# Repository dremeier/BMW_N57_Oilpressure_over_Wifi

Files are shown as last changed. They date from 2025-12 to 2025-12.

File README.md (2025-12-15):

# BMW N57 Oilpressure over WiFi

Öldruck- und Öltemperaturanzeige für BMW N57 Motoren auf Basis eines ESP32  
mit eigenem PCB, VDO-Öldrucksensor und Web-UI (Dark-OLED / Kombiinstrument-Stil).

---
## 📸 Projektüberblick

### Komplettsystem – Steuergerät & Sensor
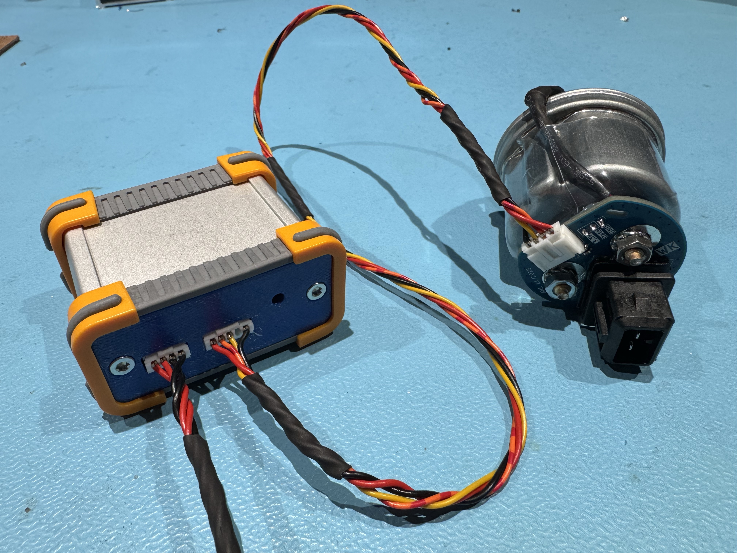
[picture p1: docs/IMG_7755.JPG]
Systemübersicht


Das System besteht aus einem ESP32-Steuergerät und einer separaten
Sensorplatine, die direkt am VDO-Öldruckgeber montiert ist.  
Die Anzeige erfolgt drahtlos über ein integriertes Web-Interface.

---
### Steuergerät (ESP32-S3 Mini)
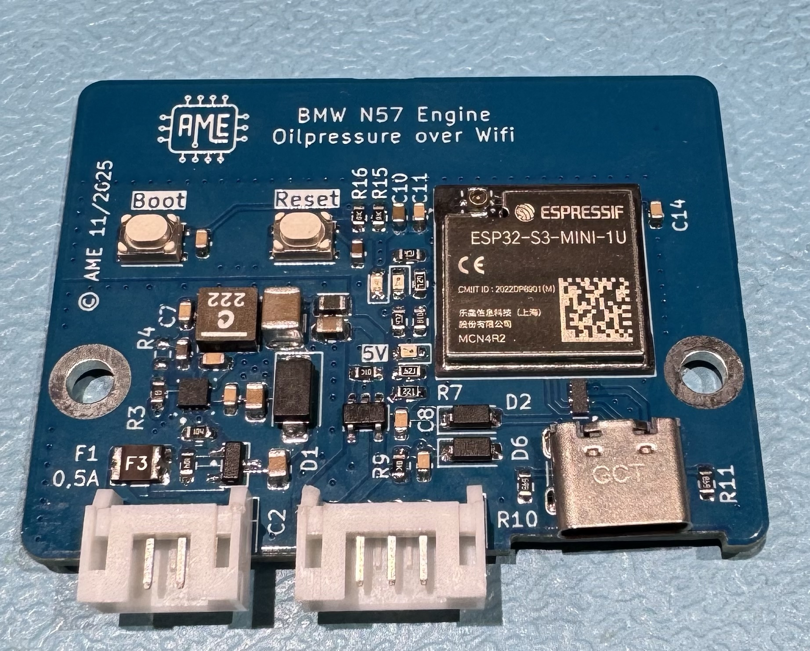
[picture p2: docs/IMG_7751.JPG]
ESP32 Steuergerät


## Features

- Messung des **Öldrucks (0–5 bar)** über VDO Druckgeber  
- Messung der **Öltemperatur** (DS18B20)  
- **ESP32 Web-Interface** (kein Internet erforderlich)  
- Automatisches **Tag-/Nacht-Design** (Grün / BMW-Amber)  
- Analoge Rundinstrument-Anzeige (Skala 0–5 bar)  
- Warnlogik:  
  - Öldruck < 0,8 bar → blinkende Warnanzeige  
  - Öltemperatur > Schwellwert → Warnfarbe  
- Integriertes **Debug-Overlay** (ADC, Spannung, Widerstände, Versionen)

---

### VDO Öldruckgeber montiert
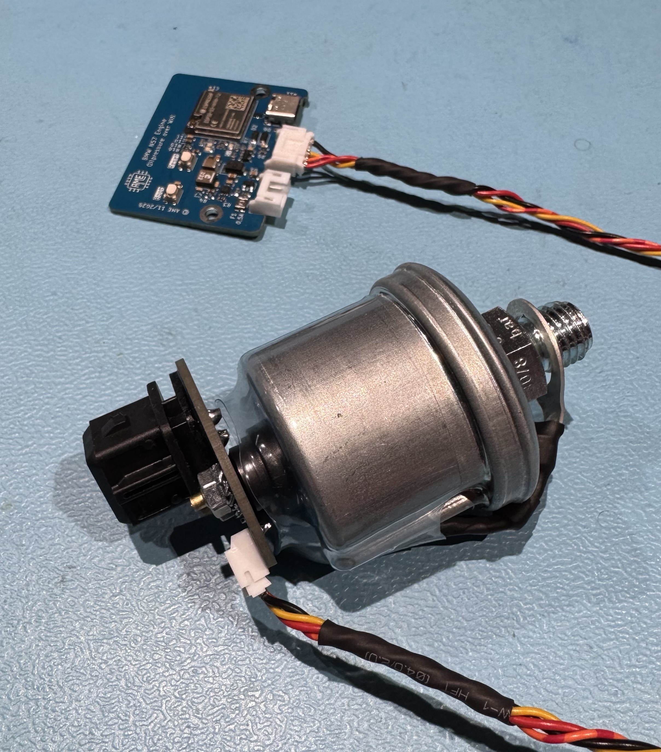
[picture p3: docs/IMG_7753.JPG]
VDO Drucksensor


OEM-naher VDO-Öldruckgeber mit integrierter Elektronik und KFZ-tauglicher
Montage.

---

## Projektstruktur

```text
BMW_N57_OILPRESSURE_OVER_WIFI/
├─ firmware/          ESP32 Firmware (PlatformIO)
├─ pcb_main/          Hauptplatine (KiCad)
├─ pcb_sensor/        Sensorplatine (KiCad)
├─ docs/              Datenblätter & Dokumentation
└─ README.md
```

---
### 3D-Render – Hauptplatine
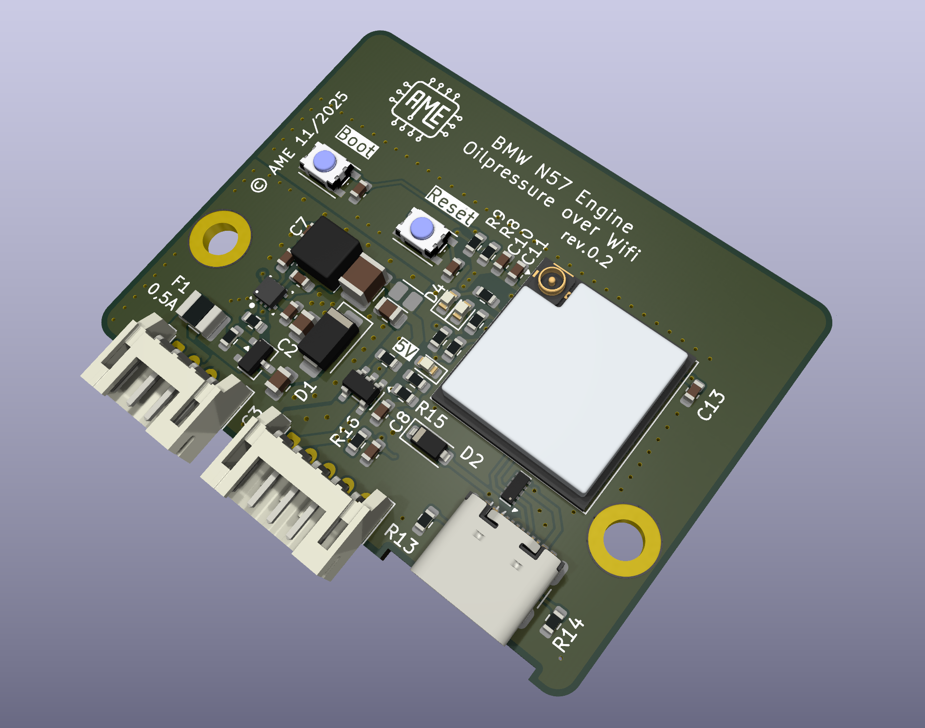
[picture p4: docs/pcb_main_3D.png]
PCB 3D Render


3D-Ansicht der Hauptplatine (KiCad).  
Kompaktes, robustes Layout für den Einsatz im Fahrzeug.

## Hardware

- ESP32 (ESP32-S3 mini)
- VDO Öldruckgeber 0–5 bar (M12x1.5)
- DS18B20 Temperatursensor
- Step‑Down‑Regler 
- Versorgung Sensor: **≈ 5,0 V**
- USB‑C zum flaschen

## 🚦 Status-LEDs

| LED | Funktion |
|----|---|
| **LED orange** | Leuchtet dauerhaft, wenn der WiFi-Access-Point aktiv ist |
| **LED blau** | Leuchtet, sobald ein Client (Smartphone / Browser) verbunden ist |

---

## Messprinzip

Der VDO-Öldruckgeber arbeitet als Widerstand gegen Masse.  
Die Messung erfolgt über einen Spannungsteiler:

```text
+5V → R_PULLUP → Rsensor → GND
```

Die Firmware berechnet:
1. ADC → Spannung (kalibriert)
2. Spannung → Rsensor
3. Rsensor → bar (VDO-Kennlinie via LUT + Interpolation)
4. IIR-Filter zur Glättung

---
### Web-UI (Live-Anzeige)
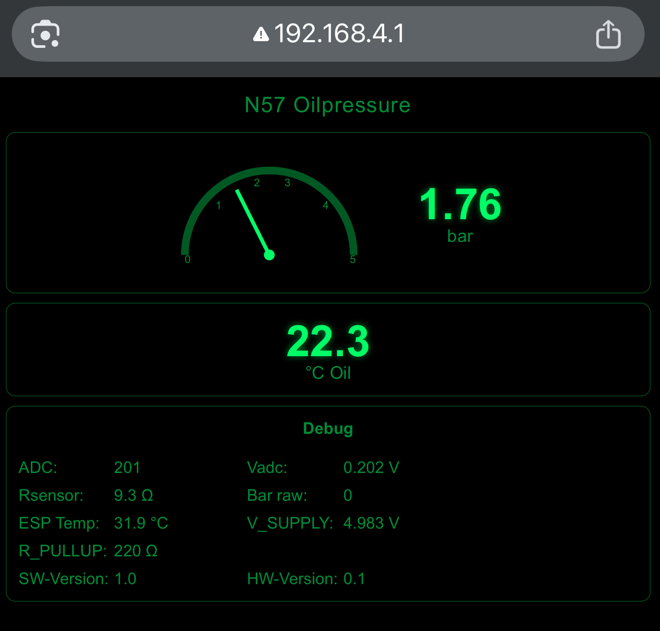
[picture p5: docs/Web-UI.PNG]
Web UI


## Web-UI

- Zugriff über ESP32 Access Point
- Anzeige:
  - Öldruck (bar)
  - Öltemperatur (°C)
  - Analoges Rundinstrument
- Debug-Bereich mit:
  - ADC
  - Vadc
  - Rsensor
  - Bar raw
  - ESP-Temperatur
  - Versorgungsspannung
  - Pullup-Widerstand
  - SW- / HW-Version

---

## Status

- Hardware: **funktionsfähig**
- Firmware: **stabil**
- Kalibrierung: **ADC + Versorgungsspannung kalibriert**
- Projektstatus: **aktiv in Entwicklung**

---

## Hinweis

Dieses Projekt ist ein **DIY-Projekt** und ersetzt keine serienmäßigen
Sicherheitsfunktionen des Fahrzeugs.

Nutzung auf eigene Verantwortung.

---

## Lizenz

Noch nicht festgelegt.

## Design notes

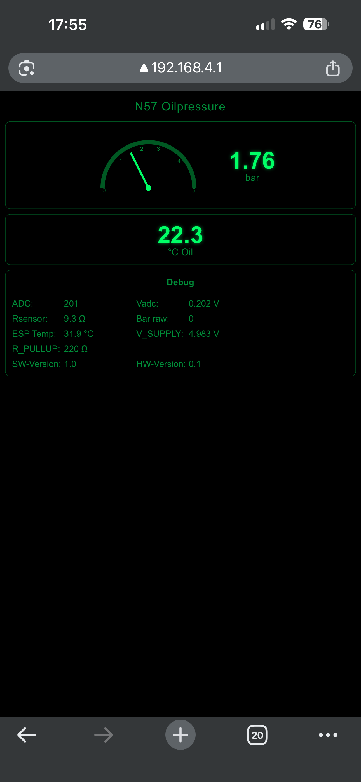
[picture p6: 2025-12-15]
docs/[Originaldateien]/Web-UI.PNG

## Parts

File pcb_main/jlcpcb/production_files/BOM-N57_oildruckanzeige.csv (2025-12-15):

Comment | Designator | Footprint | LCSC | Quantity
0H 8mOHM 5A 782853200 | FB1 | L_Eaton_MCL2012V1 | C394484 | 1
100 | R1,R8 | R_0603_1608Metric | C105588 | 2
100K | R2 | R_0603_1608Metric | C14675 | 1
100n | C7,C8 | C_0603_1608Metric | C14663 | 2
100nF | C11,C12,C14,C15,C3,C5 | C_0603_1608Metric | C14663 | 6
10K | R15,R16,R5 | R_0603_1608Metric | C98220 | 3
1210L050/30WR | F1 | Fuse_1210_3225Metric | C2154034 | 1
1uF | C4 | C_0603_1608Metric | C5199872 | 1
1μF | C13 | C_0603_1608Metric | C5199872 | 1
2.2µH XAL4020-222MEB | L1 | L_Coilcraft_XxL4040 | C3151182 | 1
220 | R7,R9 | R_0603_1608Metric | C107696 | 2
22uF/10V | C10 | C_0603_1608Metric | C86295 | 1
4,7uF | C9 | C_0805_2012Metric | C32635 | 1
4,7uF/25V | C1,C2 | C_0805_2012Metric | C98195 | 2
470 | R13 | R_0603_1608Metric | C114669 | 1
47µF/16V | C6 | C_1210_3225Metric | C77101 | 1
49K9 | R3 | R_0603_1608Metric | C100044 | 1
4K7 | R6 | R_0603_1608Metric | C99782 | 1
5K11 | R10,R11 | R_0603_1608Metric | C112314 | 2
620 | R12,R14 | R_0603_1608Metric | C137695 | 2
AP7365-33WG-7 | U2 | SOT-23-5 | C150742 | 1
D3V3XA4B10LP | U4 | Diodes_UDFN-10_1.0x2.5mm_P0.5mm | C1980462 | 1
ESP32-S3-MINI-1U-N4R2 | U3 | ESP32-S2-MINI-1U | C22356044 | 1
LMR43610MSC5RPERQ1 | U1 | LMR43610 | C5219291 | 1
PJA3441 | Q1 | SOT-23-3 | C313504 | 1
Programm | SW2 | SW_Push_1P1T_NO_Vertical_Wuerth_434133025816 | C2927789 | 1
SMAJ26CA | D1 | D_SMA | C148226 | 1
STPS140ZY | D2 | D_SOD-123 | C155662 | 1
USB_C_Receptacle_USB2.0 | J3 | USB_C_Receptacle_GCT_USB4105-xx-A_16P_TopMnt_Horizontal | C5184243 | 1
blue 5mA | D4 | LED_0603_1608Metric | C125103 | 1
grün 5mA | D3 | LED_0603_1608Metric | C2962098 | 1
reset | SW1 | SW_Push_1P1T_NO_Vertical_Wuerth_434133025816 | C2927789 | 1
yellow 5mA | D5 | LED_0603_1608Metric | C160477 | 1
12K4 | R4 | R_0603_1608Metric |  | 1
Sensor | J2 | JST_PH_S5B-PH-K_1x05_P2.00mm_Horizontal |  | 1
Power | J1 | JST_PH_S4B-PH-K_1x04_P2.00mm_Horizontal |  | 1
MountingHole_Pad | H2 | MountingHole_3.2mm_M3_ISO7380_Pad |  | 1
MountingHole_Pad | H1 | MountingHole_3.2mm_M3_ISO7380_Pad |  | 1

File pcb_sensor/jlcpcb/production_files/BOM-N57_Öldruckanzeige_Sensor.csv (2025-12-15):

Comment | Designator | Footprint | LCSC | Quantity
Conn_01x02_Pin | J3 | KFZ-2-POL-P5_DJ7021B-3.5-1121 |  | 1
1μF | C2 | C_0603_1608Metric_Pad1.08x0.95mm_HandSolder |  | 1
DS18B20 | J2 | PinHeader_1x03_P2.00mm_Vertical |  | 1
100nF | C1 | C_0603_1608Metric_Pad1.08x0.95mm_HandSolder |  | 1
PressSensor | J1 | JST_PH_S4B-PH-K_1x04_P2.00mm_Horizontal |  | 1

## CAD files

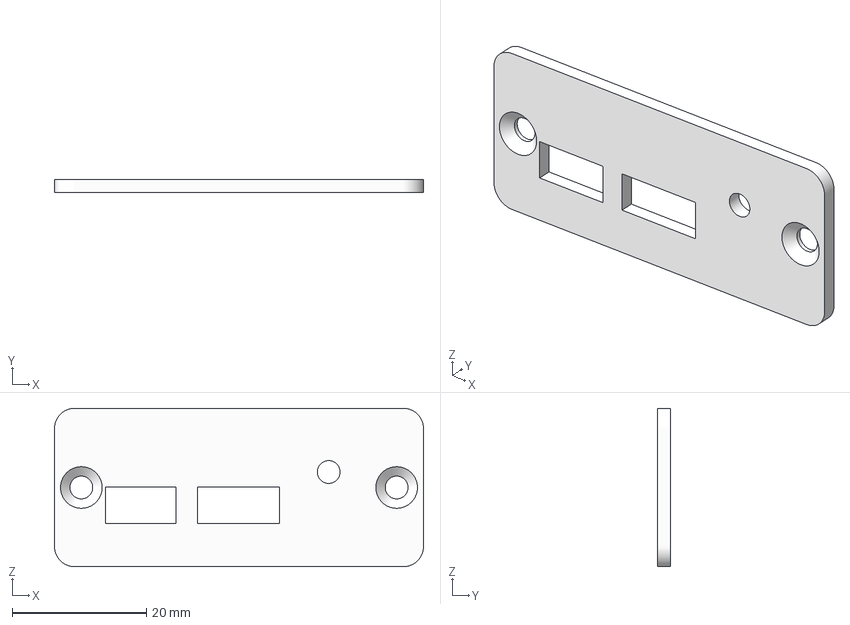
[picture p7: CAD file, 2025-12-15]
docs/BMW-N57_Oilpress_Case v3.3mf
55.0 x 2.00 x 23.6 mm

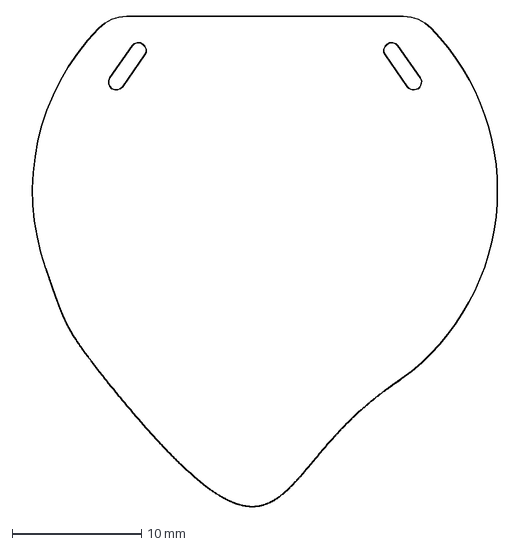
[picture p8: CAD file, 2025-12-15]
pcb_sensor/Öldrucksensor PCB-KFZ.dxf
37.8 x 38.0 mm

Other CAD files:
docs/BMW-N57_Oilpress_Case.f3d

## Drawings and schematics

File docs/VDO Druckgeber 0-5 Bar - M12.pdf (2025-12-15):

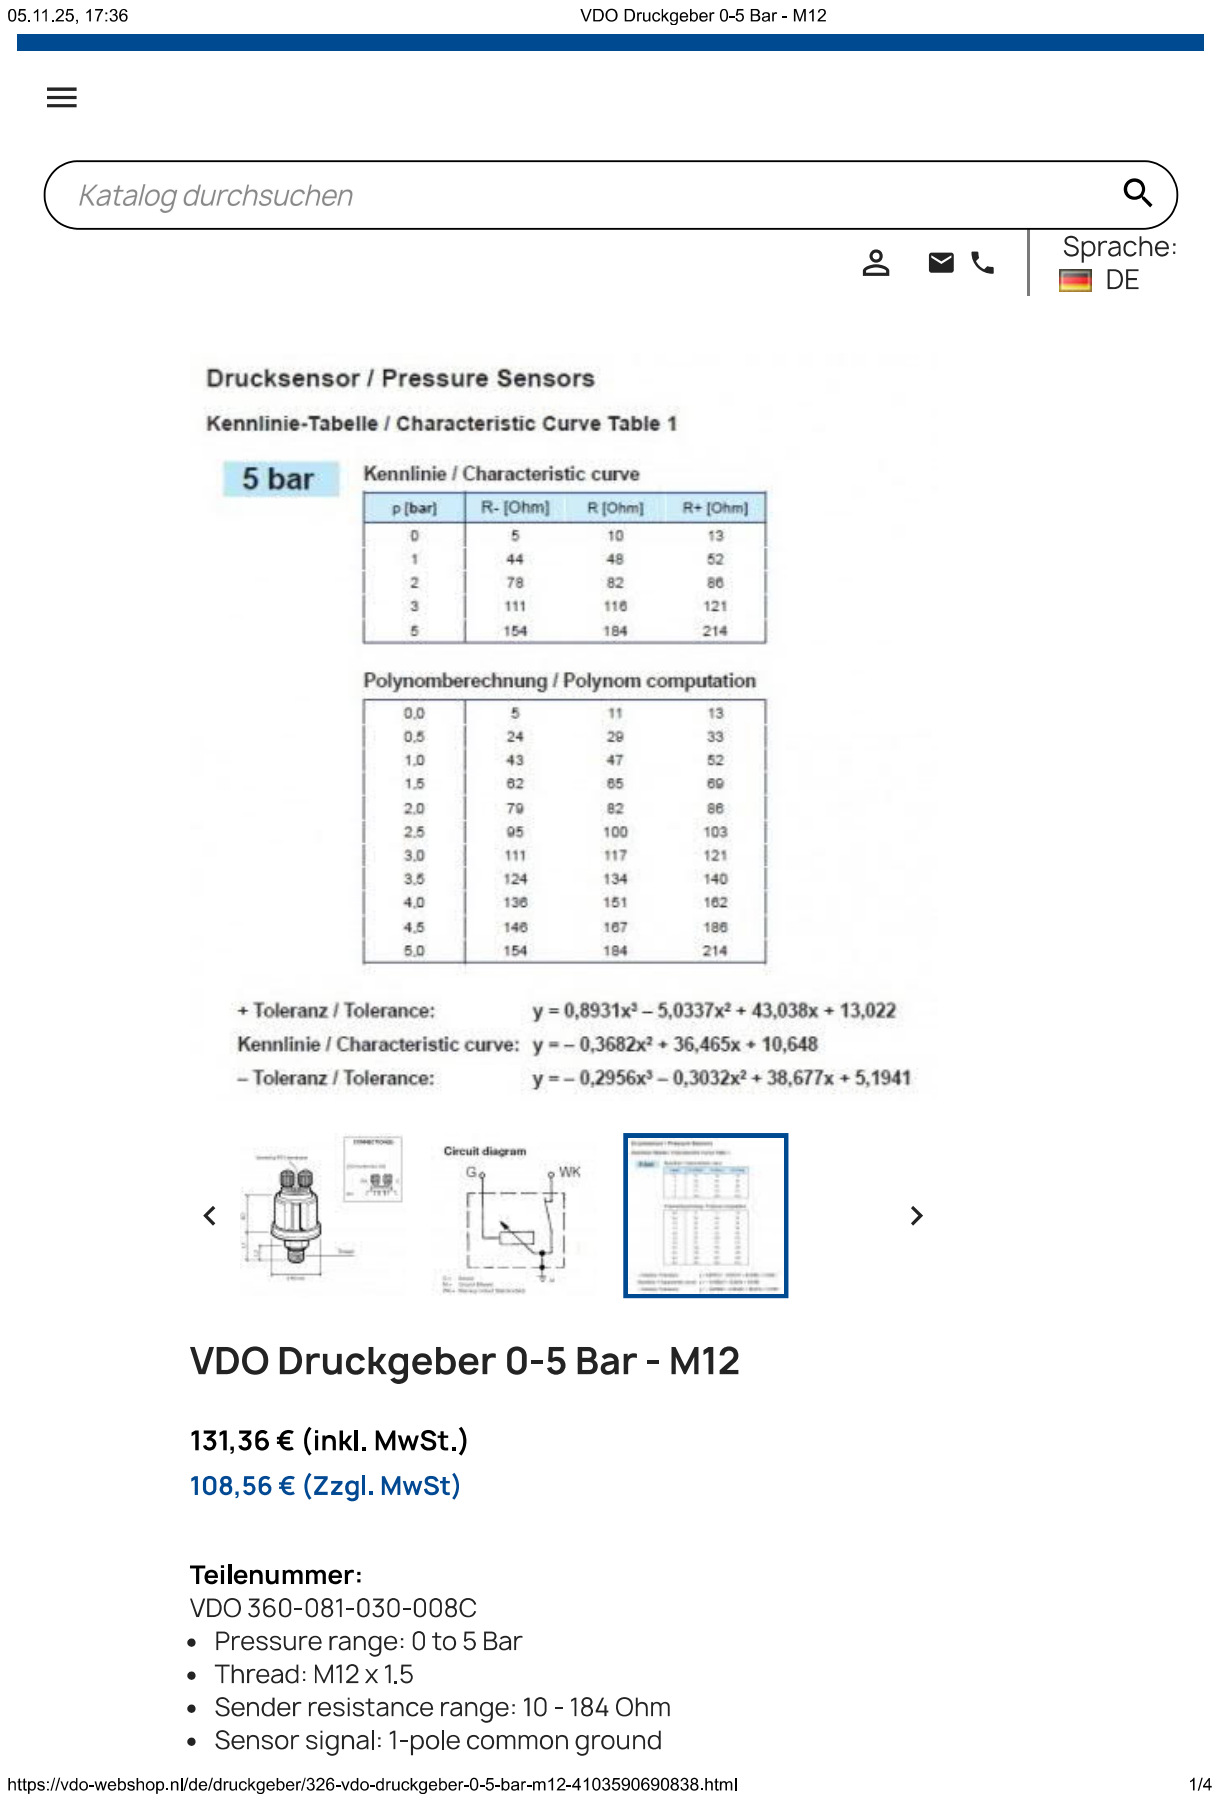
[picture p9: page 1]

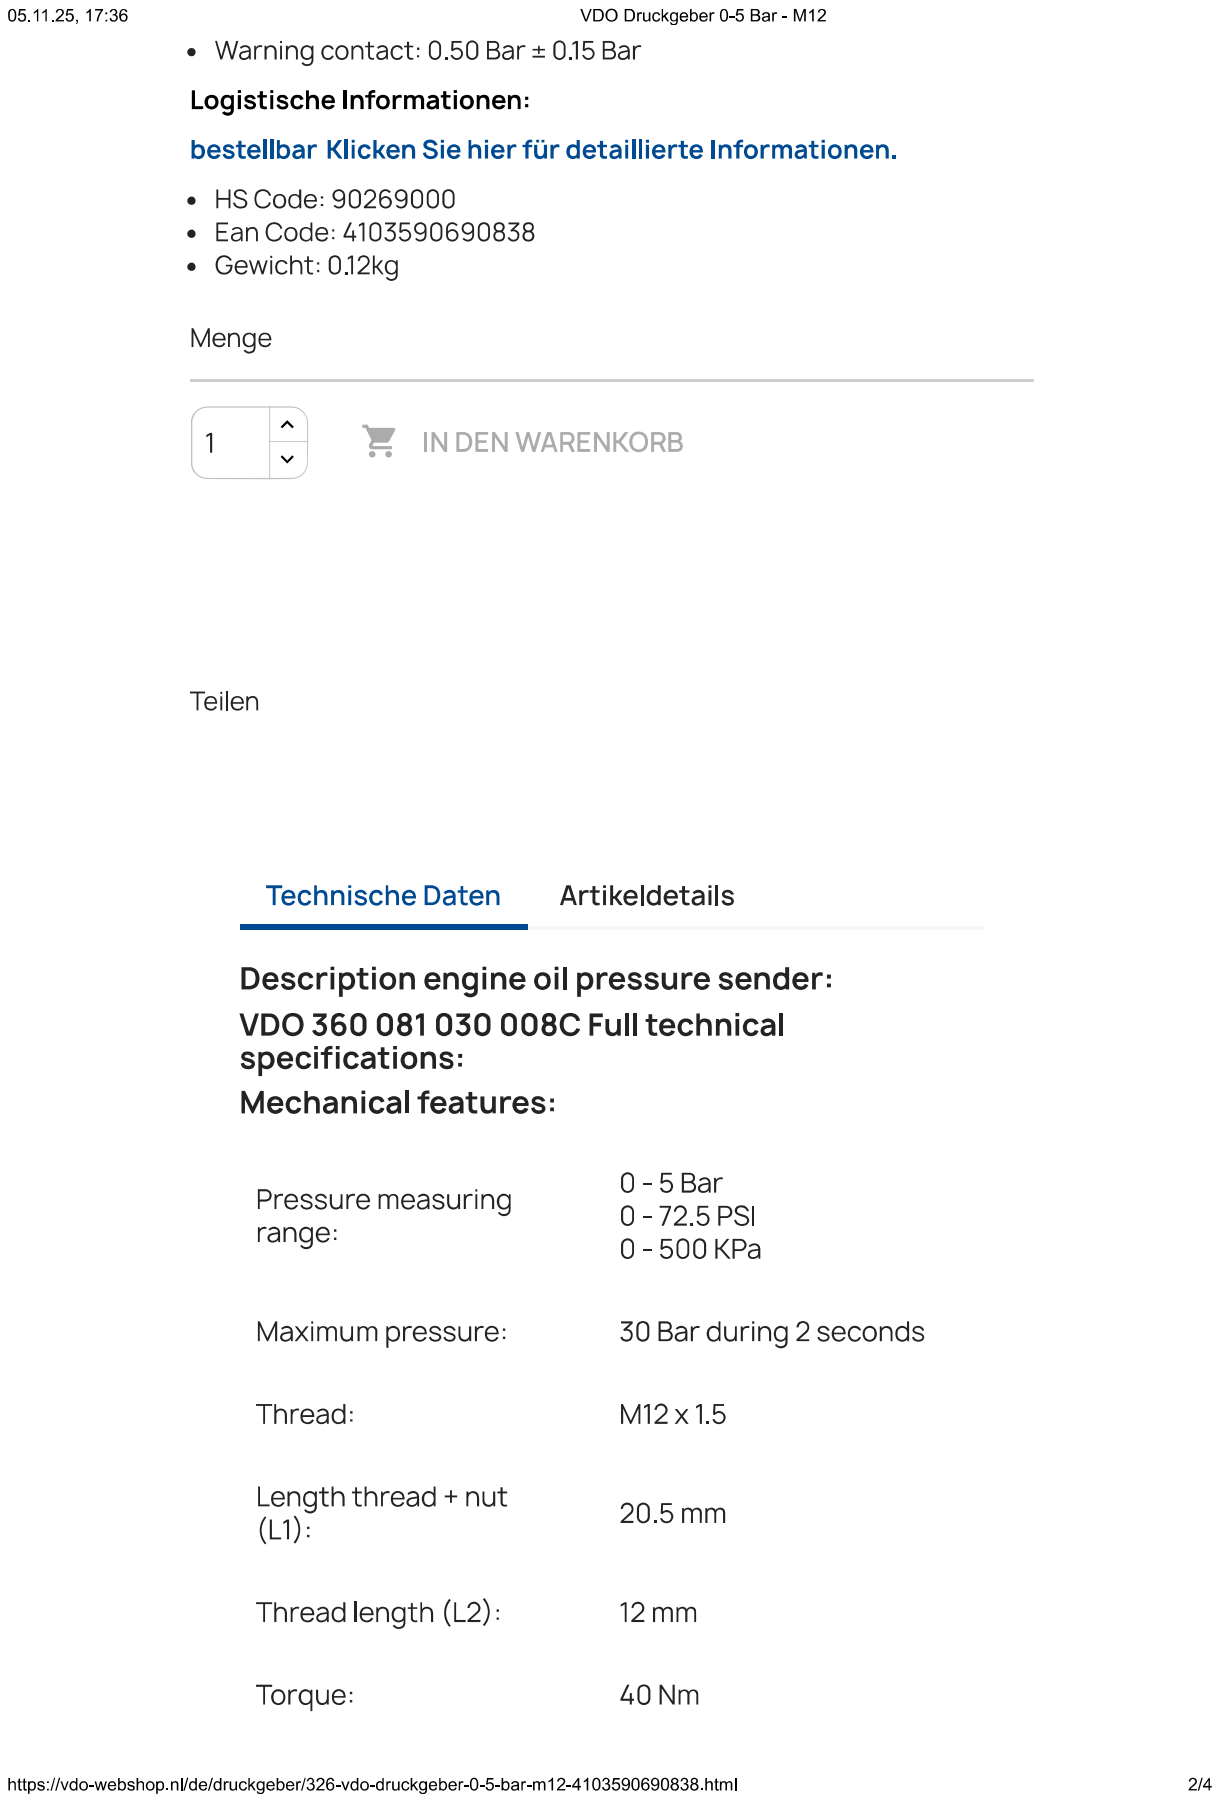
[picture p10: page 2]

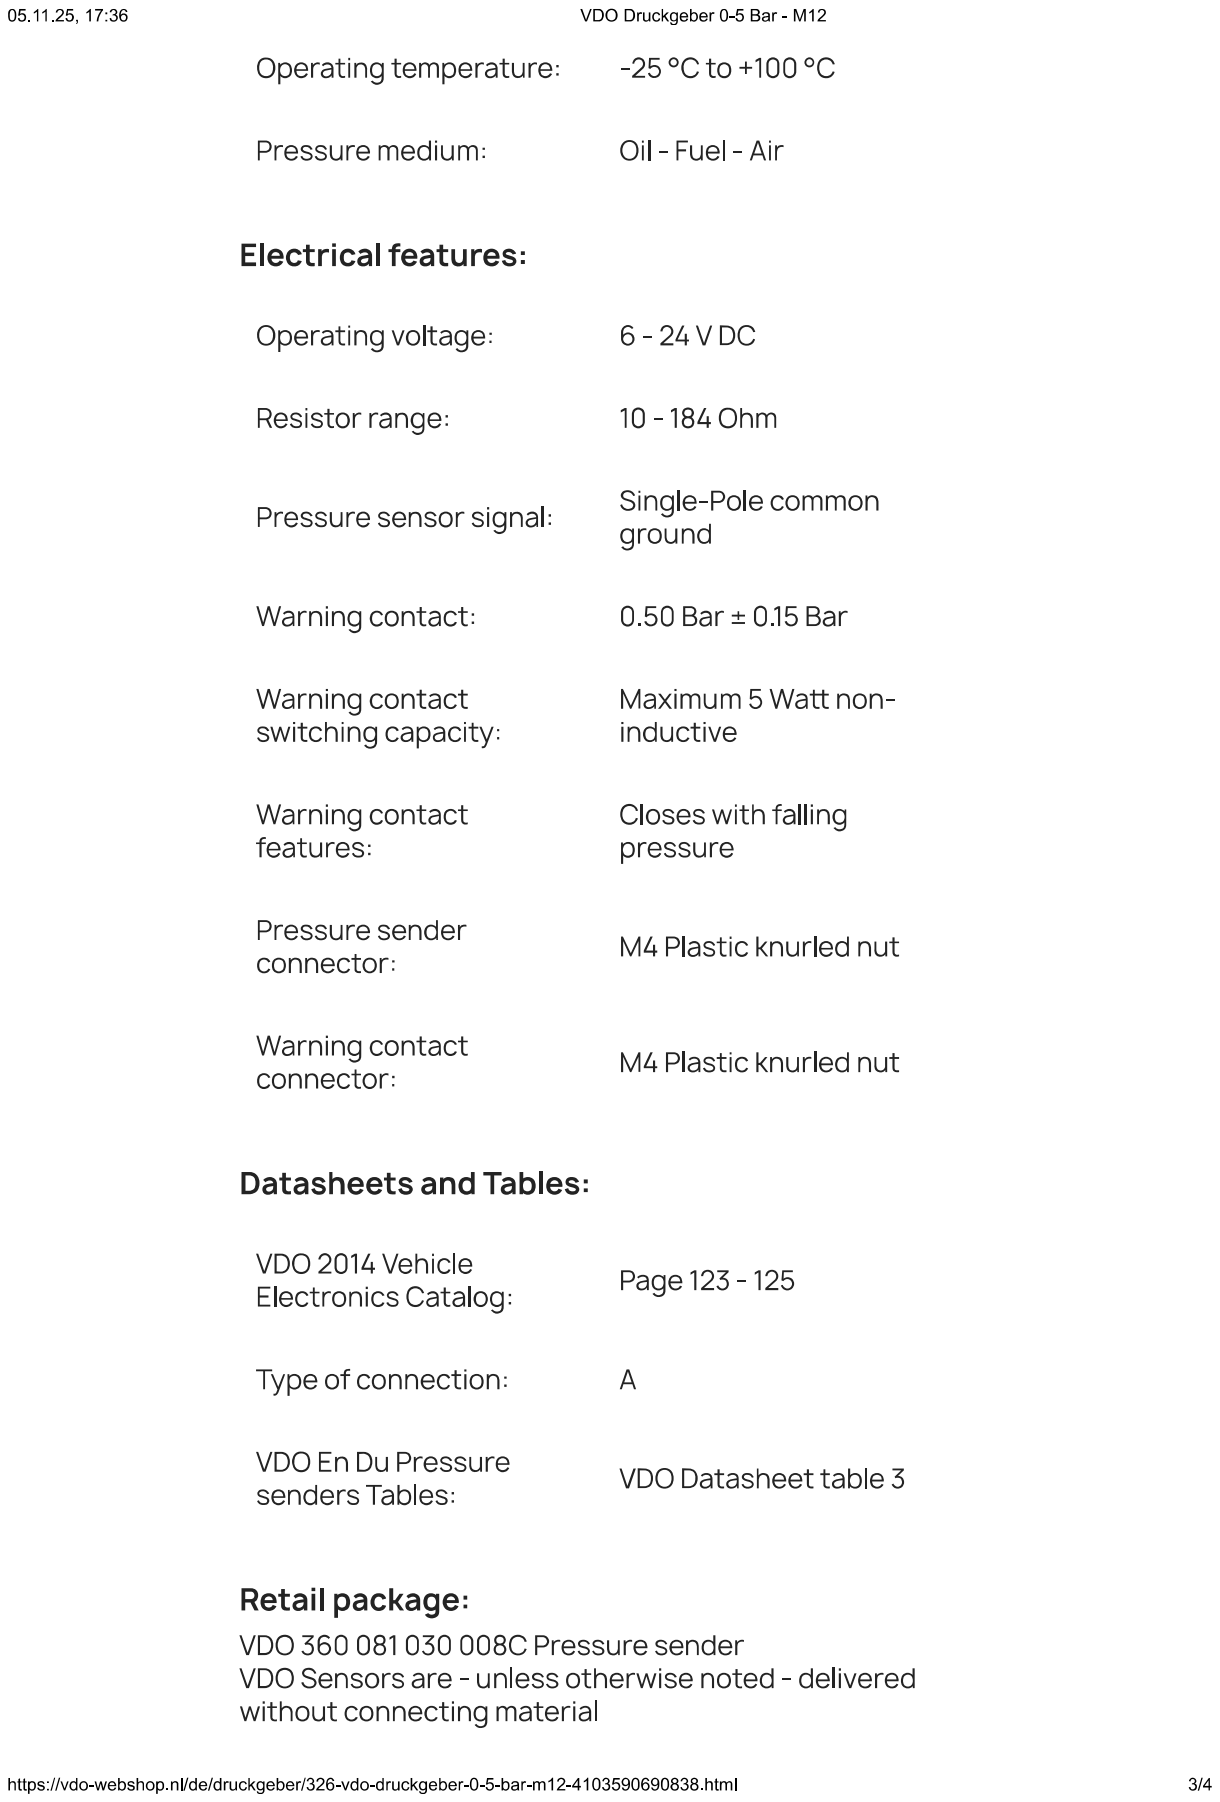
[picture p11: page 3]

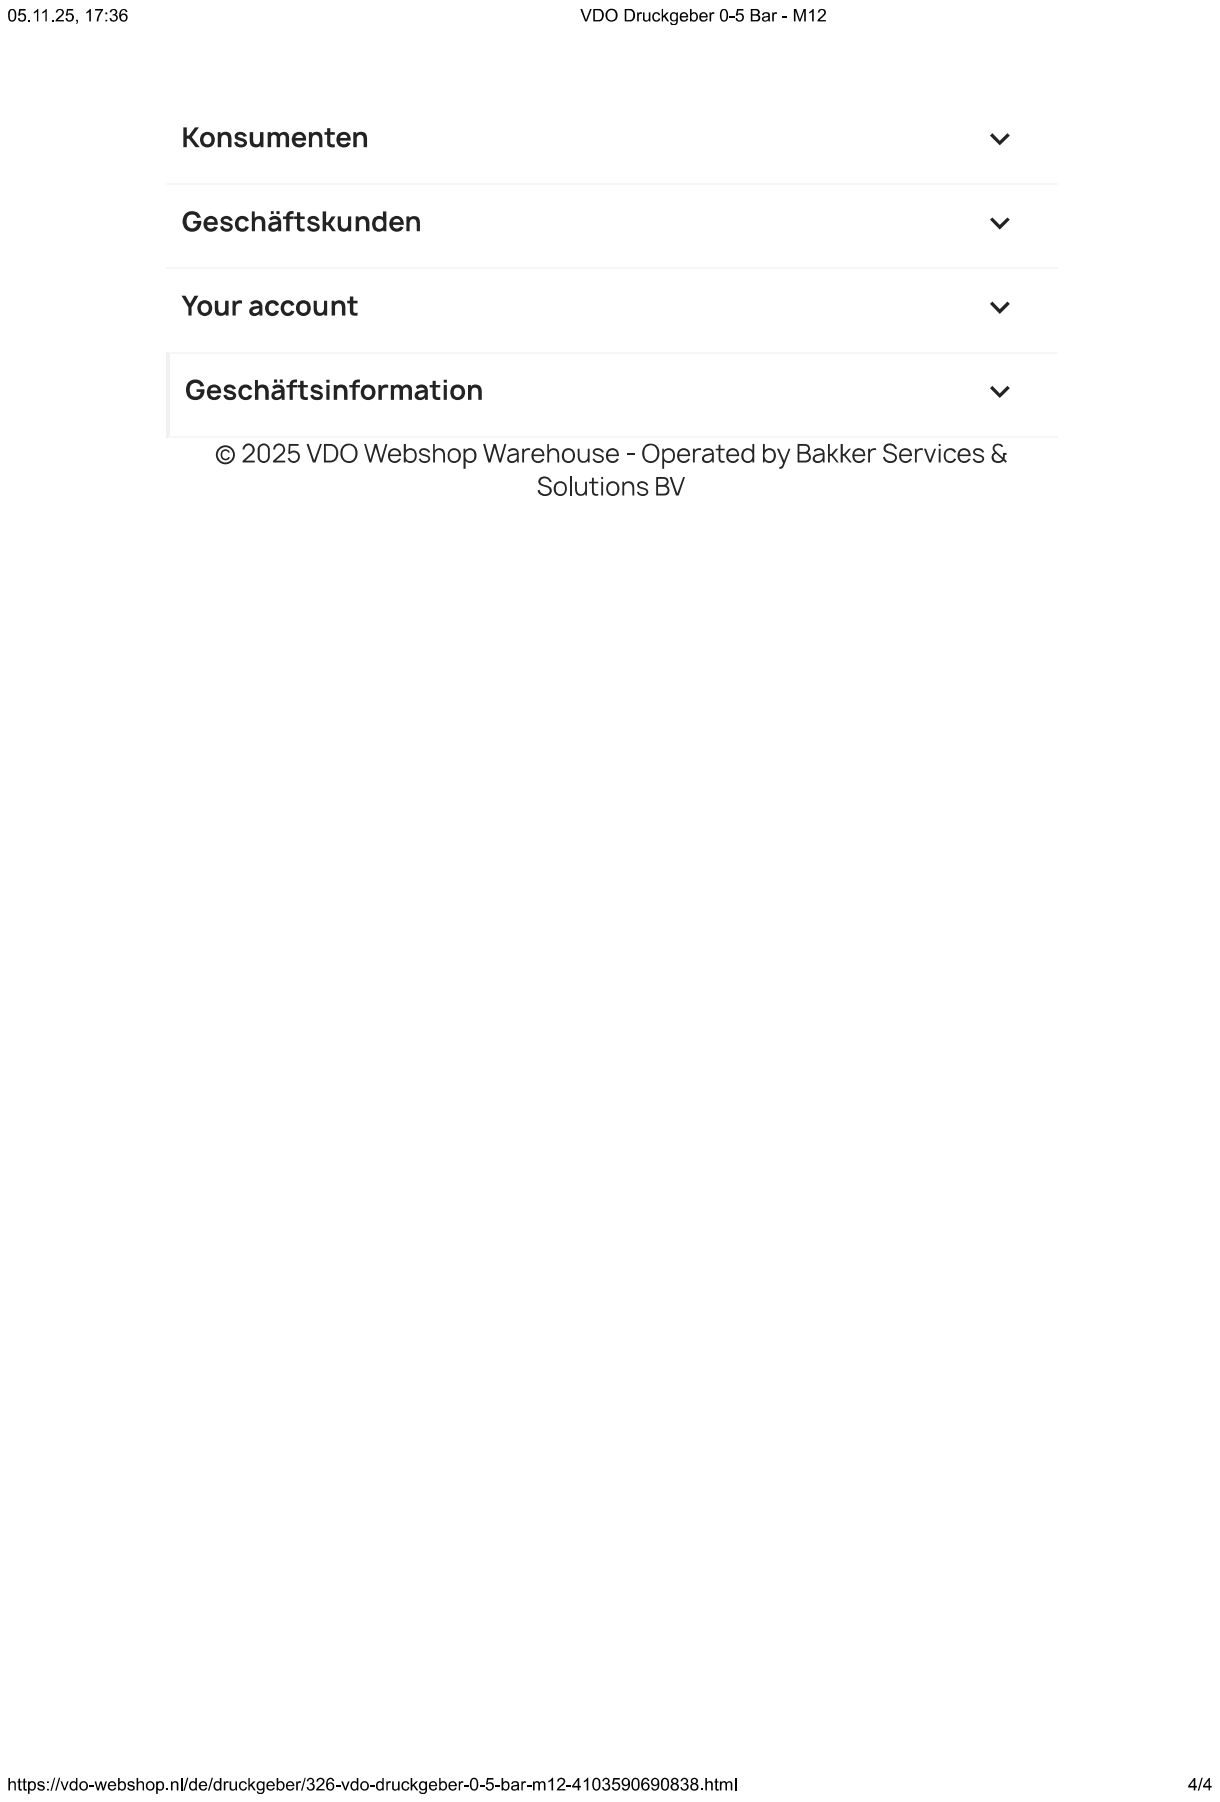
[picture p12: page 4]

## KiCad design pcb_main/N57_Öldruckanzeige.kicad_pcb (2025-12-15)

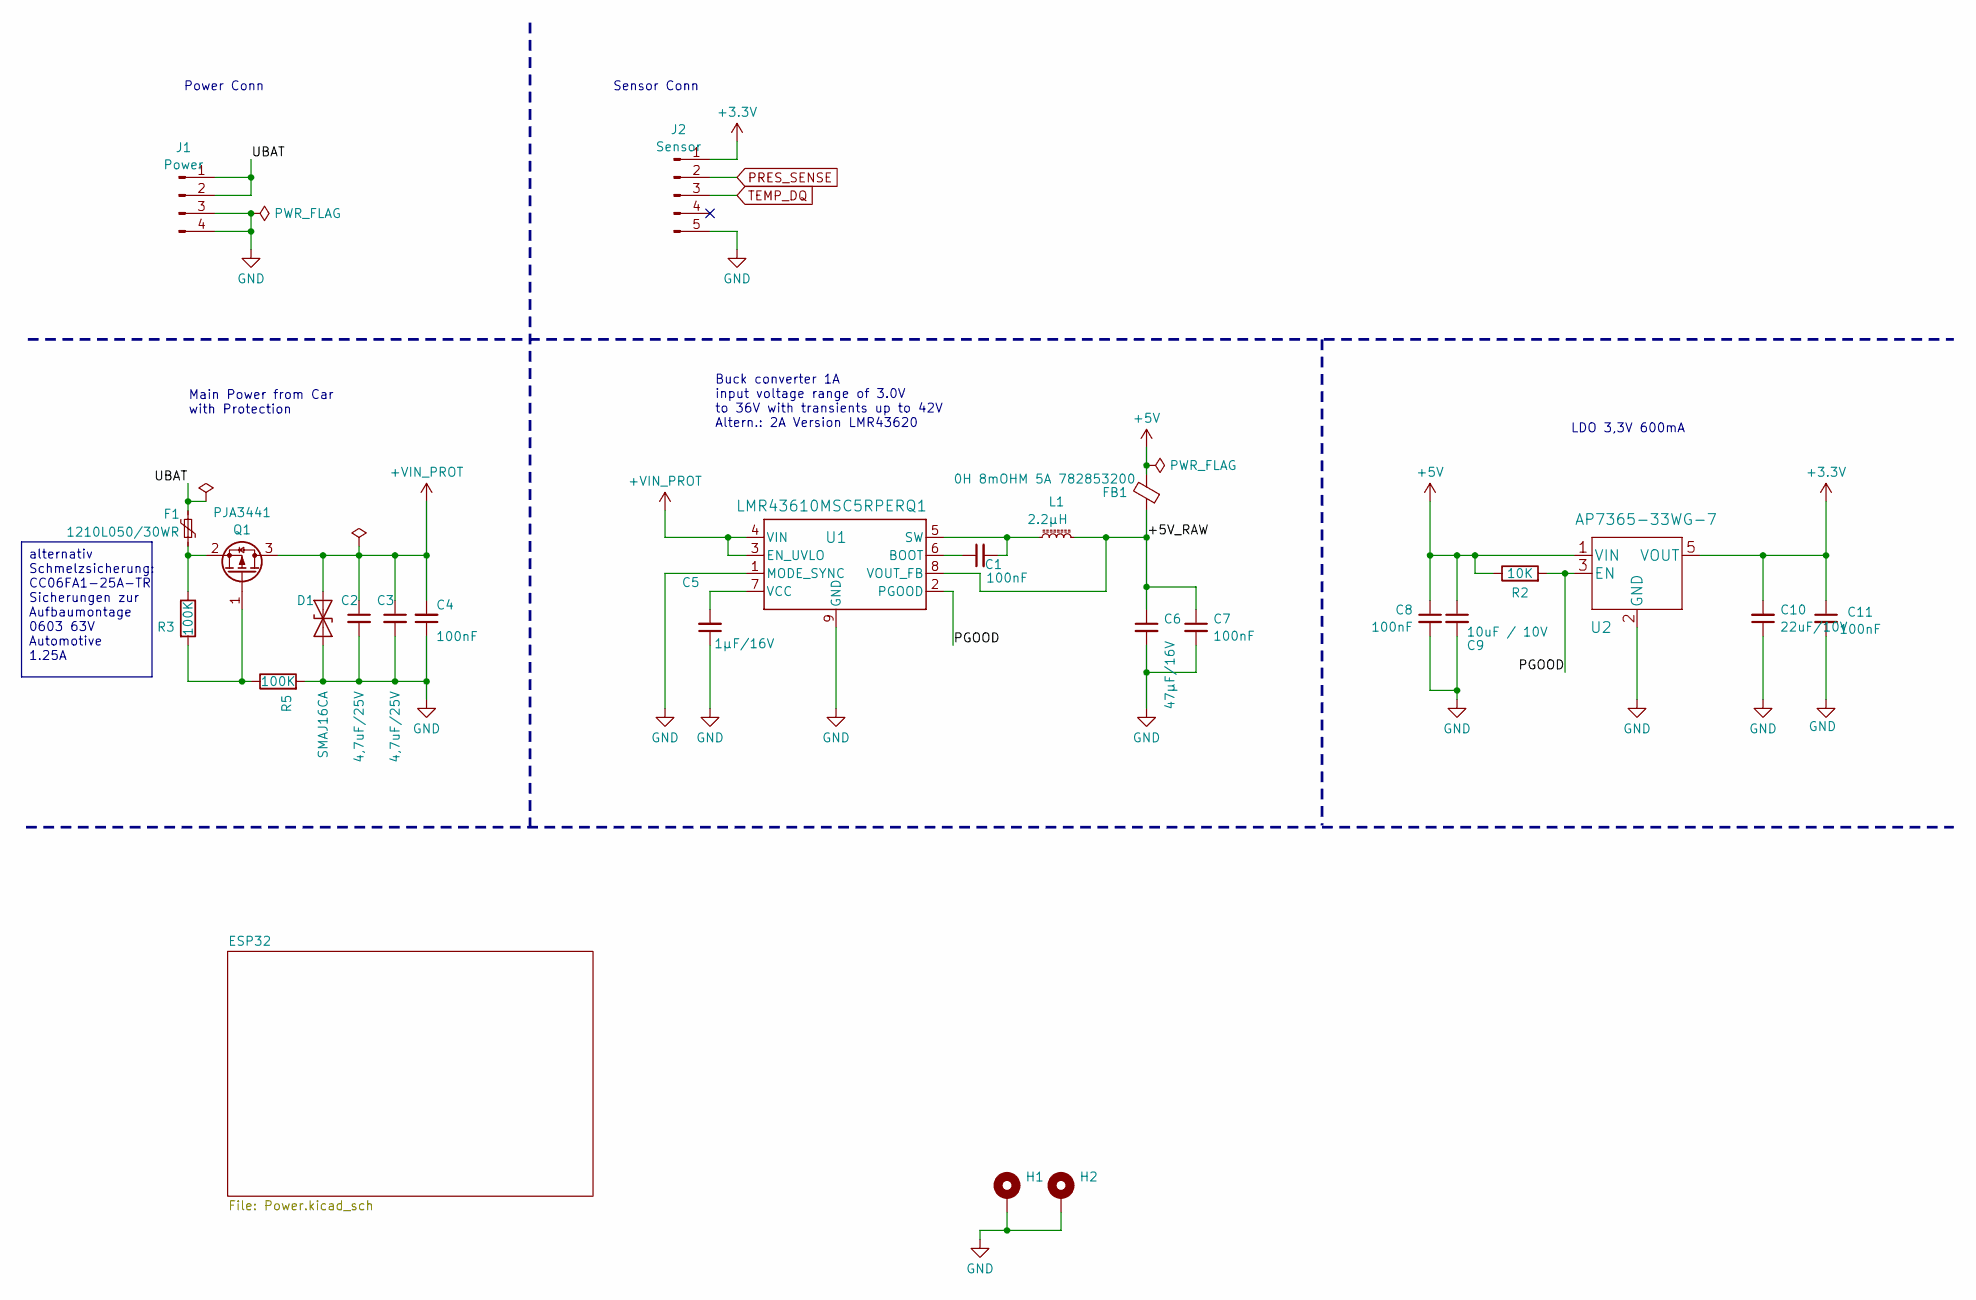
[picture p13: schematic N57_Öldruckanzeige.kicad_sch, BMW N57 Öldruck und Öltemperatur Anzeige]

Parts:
C1, C4, C7, C8, C11: 100nF; C_0603_1608Metric; my_parts_ID 5; LCSC C14663
C2, C3: 4,7uF/25V; C_0805_2012Metric; my_parts_ID 37; LCSC C98195
C5: 1μF/16V; C_0603_1608Metric; my_parts_ID 22; LCSC C5199872
C6: 47µF/16V; C_1210_3225Metric; Part Number MBASE32MAB5476KPNDT1; LCSC C77101
C9: 10uF / 10V; C_0805_2012Metric; Part Number GRM21BR71A106KA73K; LCSC C32635
C10: 22uF/10V; C_0603_1608Metric; Part Number GRT188R61A226ME13D; LCSC C86295
D1: SMAJ16CA; D_SMA; Part Number SMAJ40CA-TR; LCSC C148226
F1: 1210L050/30WR; Fuse_1210_3225Metric; Part Number 1210L050/30WR; LCSC C2154034
FB1: 0H 8mOHM 5A 782853200; L_Eaton_MCL2012V1; my_parts_ID 80; LCSC C394484
H1, H2: MountingHole_Pad; MountingHole_3.2mm_M3_ISO7380_Pad
J1: Power; JST_PH_S4B-PH-K_1x04_P2.00mm_Horizontal
J2: Sensor; JST_PH_S5B-PH-K_1x05_P2.00mm_Horizontal
L1: 2.2µH; L_Coilcraft_XxL4040; Part Number XEL4020-222MEC; LCSC C3151182
Q1: PJA3441; SOT-23-3; my_parts_ID 296; LCSC C313504
R2: 10K; R_0603_1608Metric; my_parts_ID 236; LCSC C98220
R3: 100K; R_0603_1608Metric; my_parts_ID 200; LCSC C98220
R5: 100K; R_0603_1608Metric; my_parts_ID 250; LCSC C98220
U1: LMR43610MSC5RPERQ1; LMR43610; Part Number LM61495Q5RPHRQ1; LCSC C5219291
U2: AP7365-33WG-7; SOT-23-5; Part Number AP7365-33WG-7; LCSC C150742

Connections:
+3.3V: C10.2, C11.1, J2.1, U2.5 (VOUT); also elsewhere on the board
+5V: C8.1, C9.1, FB1.2, R2.1, U2.1 (VIN); also elsewhere on the board
+VIN_PROT: C2.1, C3.1, C4.2, D1.2 (A2), Q1.3 (D), U1.3 (EN_UVLO), U1.4 (VIN)
/+5V_RAW: C6.1, C7.1, FB1.1, L1.2, U1.8 (VOUT_FB)
/PGOOD: R2.2, U1.2 (PGOOD), U2.3 (EN)
/UBAT: F1.2, J1.1, J1.2
GND: C2.2, C3.2, C4.1, C5.1, C6.2, C7.2, C8.2, C9.2, C10.1, C11.2, D1.1 (A1), H1.1, H2.1, J1.3, J1.4, J2.5, R5.2, U1.1 (MODE_SYNC), U1.9 (GND), U2.2 (GND); also elsewhere on the board
unnamed: Q1.1 (G), R3.2, R5.1
unnamed: F1.1, Q1.2 (S), R3.1
unnamed: C1.1, U1.6 (BOOT)
unnamed: C1.2, L1.1, U1.5 (SW)
unnamed: C5.2, U1.7 (VCC)
PRES_SENSE: J2.2; also elsewhere on the board
TEMP_DQ: J2.3; also elsewhere on the board

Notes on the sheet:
Sensor Conn
Main Power from Car with Protection
Power Conn
LDO 3,3V 600mA
Buck converter 1A input voltage range of 3.0V to 36V with transients up to 42V Altern.: 2A Version LMR43620
alternativ Schmelzsicherung: CC06FA1-25A-TR Sicherungen zur Aufbaumontage 0603 63V Automotive 1.25A

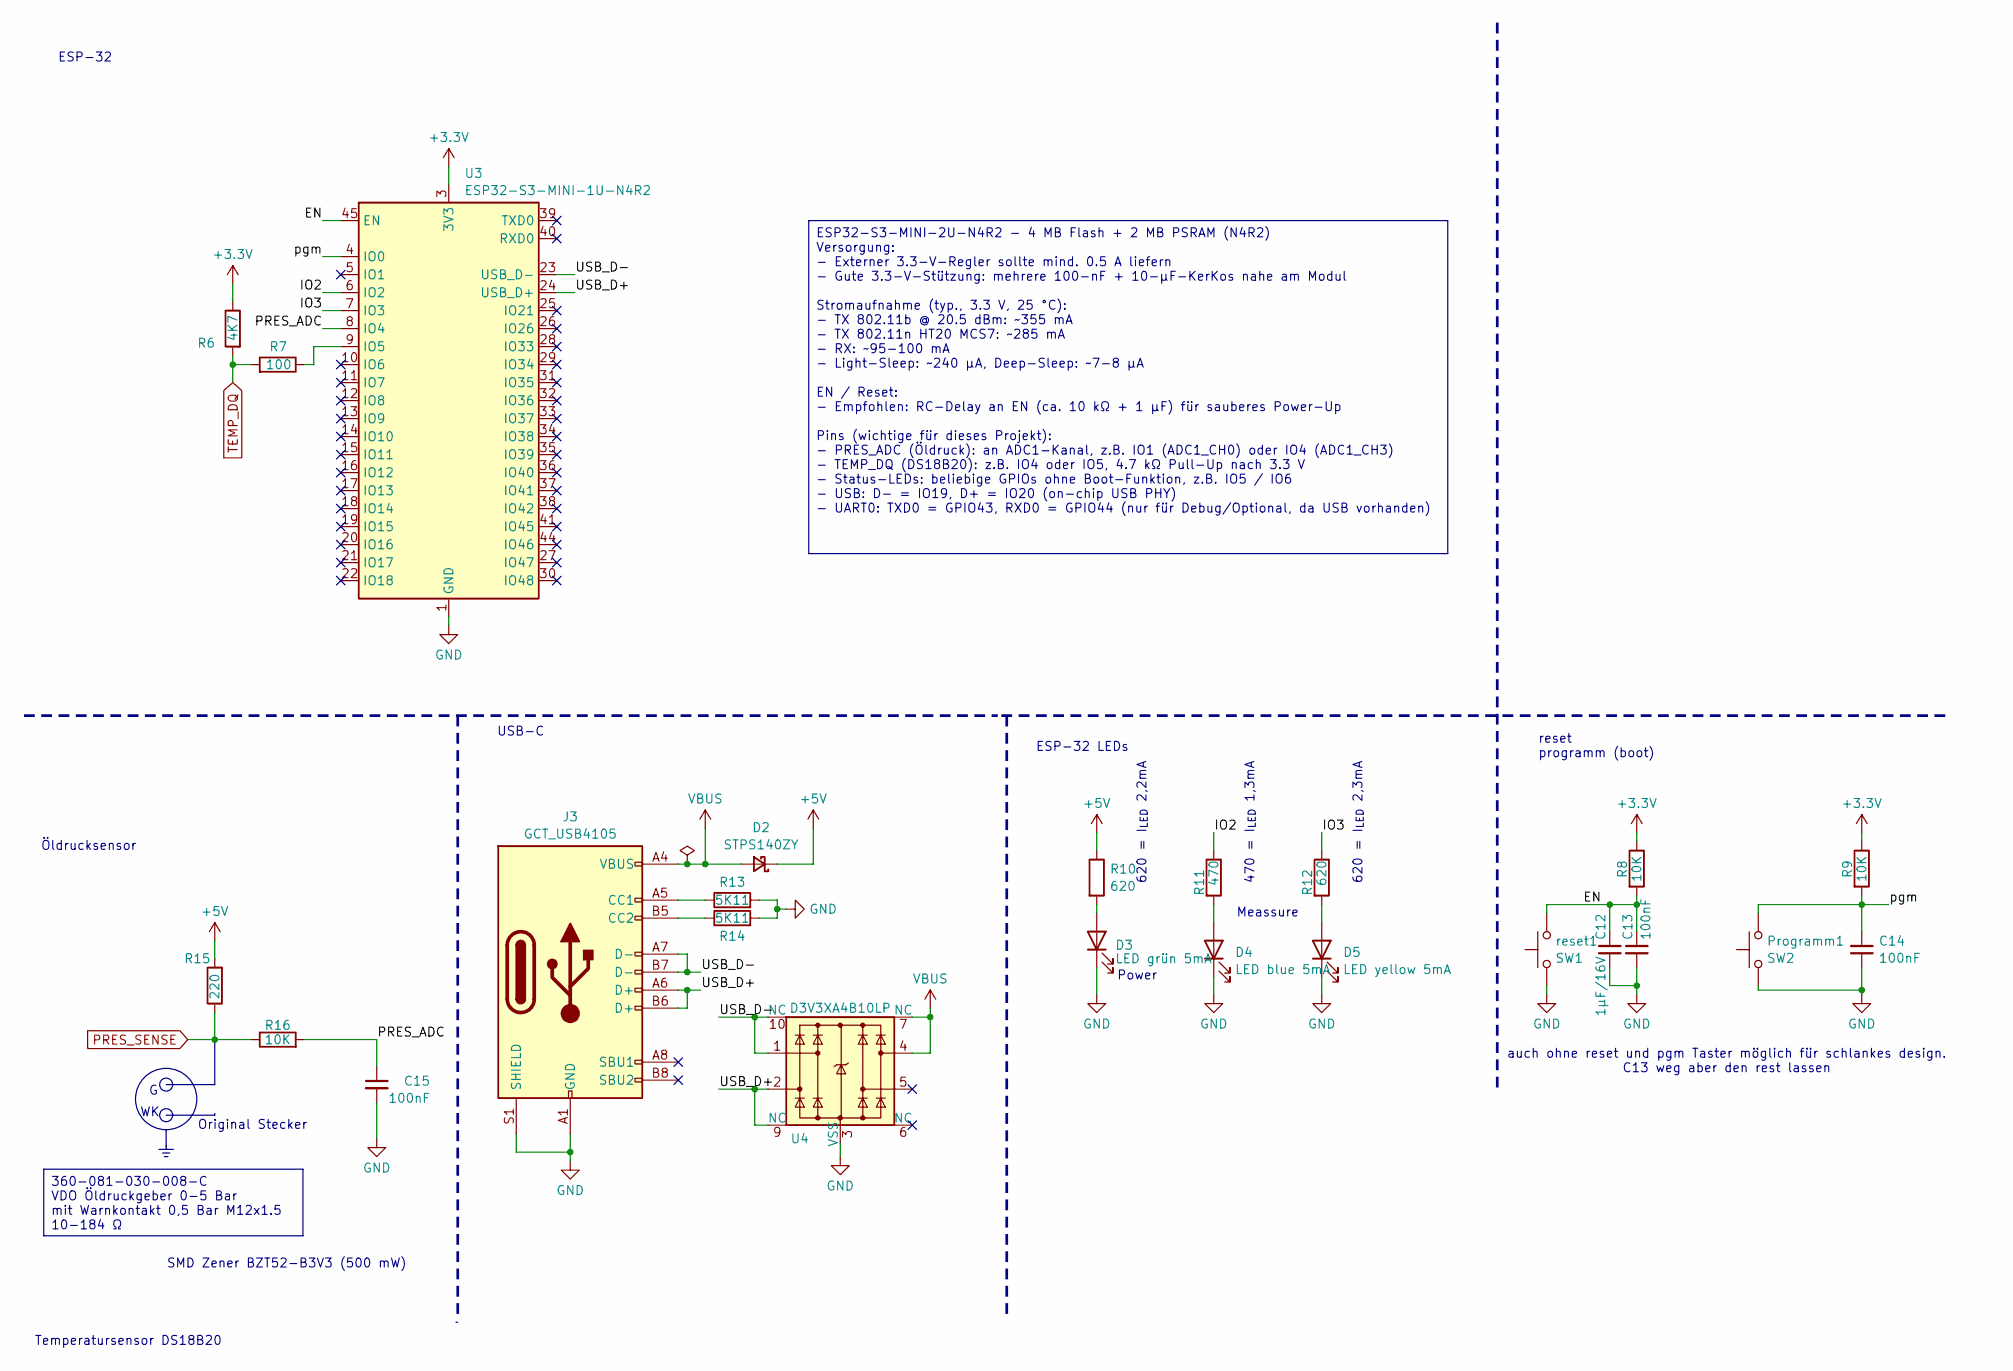
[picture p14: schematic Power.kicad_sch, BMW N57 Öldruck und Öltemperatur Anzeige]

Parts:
C12: 1μF/16V; C_0603_1608Metric; my_parts_ID 22; LCSC C5199872
C13, C14, C15: 100nF; C_0603_1608Metric; my_parts_ID 5; LCSC C14663
D2: STPS140ZY; D_SOD-123; my_parts_ID 71; LCSC C155662
D3: LED grün 5mA; LED_0603_1608Metric; my_parts_ID 184; LCSC C2962098
D4: LED blue 5mA; LED_0603_1608Metric; my_parts_ID 182; LCSC C125103
D5: LED yellow 5mA; LED_0603_1608Metric; my_parts_ID 183; LCSC C160477
J3: GCT_USB4105; USB_C_Receptacle_GCT_USB4105-xx-A_16P_TopMnt_Horizontal; Part Number USB4105-GF-A-120; LCSC C5184243
Programm1: SW2; SW_Push_1P1T_NO_Vertical_Wuerth_434133025816; Part Number RKB2SJK250SMTR; LCSC C2927789
R6: 4K7; R_0603_1608Metric; my_parts_ID 246; LCSC C99782
R7: 100; R_0603_1608Metric; my_parts_ID 200; LCSC C105588
R8, R9: 10K; R_0603_1608Metric; my_parts_ID 236; LCSC C98220
R10, R12: 620; R_0603_1608Metric; my_parts_ID 220; LCSC C137695
R11: 470; R_0603_1608Metric; my_parts_ID 216; LCSC C114669
R13, R14: 5K11; R_0603_1608Metric; my_parts_ID 233; LCSC C112314
R15: 220; R_0603_1608Metric; my_parts_ID 207; LCSC C107696
R16: 10K; R_0603_1608Metric; my_parts_ID 207; LCSC C107696
U3: ESP32-S3-MINI-1U-N4R2; ESP32-S2-MINI-1U; my_parts_ID 298; LCSC C22356044
U4: D3V3XA4B10LP; Diodes_UDFN-10_1.0x2.5mm_P0.5mm; Part Number D3V3XA4B10LP-7; LCSC C1980462
reset1: SW1; SW_Push_1P1T_NO_Vertical_Wuerth_434133025816; Part Number RKB2SJK250SMTR; LCSC C2927789

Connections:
+3.3V: R6.1, R8.1, R9.1, U3.3 (3V3); also elsewhere on the board
+5V: D2.1 (K), R10.1, R15.2; also elsewhere on the board
/ESP32/EN: C12.2, C13.2, R8.2, U3.45 (EN), reset1.2
/ESP32/IO2: R11.1, U3.6 (IO2)
/ESP32/IO3: R12.1, U3.7 (IO3)
/ESP32/PRES_ADC: C15.1, R16.2, U3.8 (IO4)
/ESP32/USB_D+: J3.A6 (D+), J3.B6 (D+), U3.24 (USB_D+), U4.2, U4.9 (NC)
/ESP32/USB_D-: J3.A7 (D-), J3.B7 (D-), U3.23 (USB_D-), U4.1, U4.10 (NC)
/ESP32/pgm: C14.2, Programm1.2, R9.2, U3.4 (IO0)
GND: C12.1, C13.1, C14.1, C15.2, D3.1 (K), D4.1 (K), D5.1 (K), J3.A1 (GND), J3.A12 (GND), J3.B1 (GND), J3.B12 (GND), J3.S1 (SHIELD), Programm1.1, R13.2, R14.2, U3.1 (GND), U3.2 (GND), U3.42 (GND), U3.43 (GND), U3.46 (GND), U3.47 (GND), U3.48 (GND), U3.49 (GND), U3.50 (GND), U3.51 (GND), U3.52 (GND), U3.53 (GND), U3.54 (GND), U3.55 (GND), U3.56 (GND), U3.57 (GND), U3.58 (GND), U3.59 (GND), U3.60 (GND), U3.61 (GND), U3.62 (GND), U3.63 (GND), U3.64 (GND), U3.65 (GND), U4.3 (VSS), reset1.1; also elsewhere on the board
unnamed: D3.2 (A), R10.2
unnamed: D4.2 (A), R11.2
unnamed: D5.2 (A), R12.2
unnamed: J3.A5 (CC1), R13.1
unnamed: J3.B5 (CC2), R14.1
unnamed: R7.1, U3.9 (IO5)
PRES_SENSE: R15.1, R16.1; also elsewhere on the board
TEMP_DQ: R6.2, R7.2; also elsewhere on the board
VBUS: D2.2 (A), J3.A4 (VBUS), J3.A9 (VBUS), J3.B4 (VBUS), J3.B9 (VBUS), U4.4, U4.7 (NC)

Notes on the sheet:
auch ohne reset und pgm Taster möglich für schlankes design. C13 weg aber den rest lassen
Meassure
Temperatursensor DS18B20
reset programm (boot)
ESP-32
620 = I_{LED} 2,2mA
Power
ESP-32 LEDs
620 = I_{LED} 2,3mA
SMD Zener BZT52-B3V3 (500 mW)
Original Stecker
Öldrucksensor
470 = I_{LED} 1,3mA
USB-C
ESP32-S3-MINI-2U-N4R2 - 4 MB Flash + 2 MB PSRAM (N4R2) Versorgung: - Externer 3.3-V-Regler sollte mind. 0.5 A liefern - Gute 3.3-V-Stützung: mehrere 100-nF + 10-µF-KerKos nahe am Modul Stromaufnahme (typ., 3.3 V, 25 °C): - TX 802.11b @ 20.5 dBm: ~355 mA - TX 802.11n HT20 MCS7: ~285 mA - RX: ~95-100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
360-081-030-008-C VDO Öldruckgeber 0-5 Bar mit Warnkontakt 0,5 Bar M12x1.5 10-184 Ω

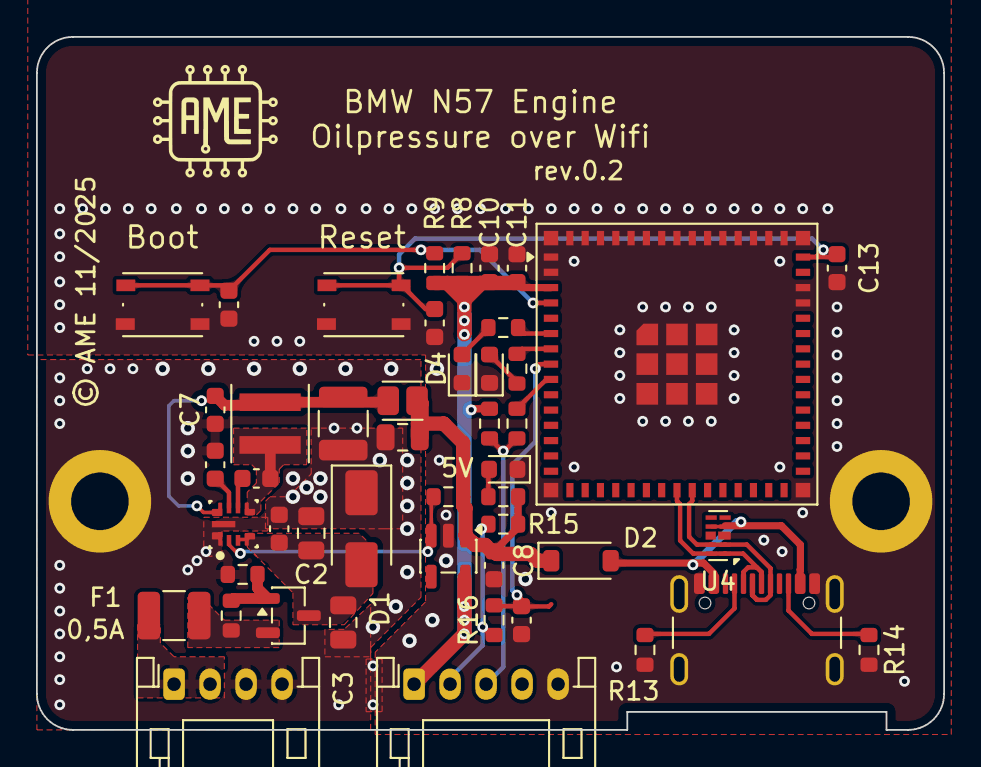
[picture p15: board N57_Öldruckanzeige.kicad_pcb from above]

Board: 2 copper layers, 50.4 x 38.5 mm, 49 parts (0 on the bottom side), 28 nets.

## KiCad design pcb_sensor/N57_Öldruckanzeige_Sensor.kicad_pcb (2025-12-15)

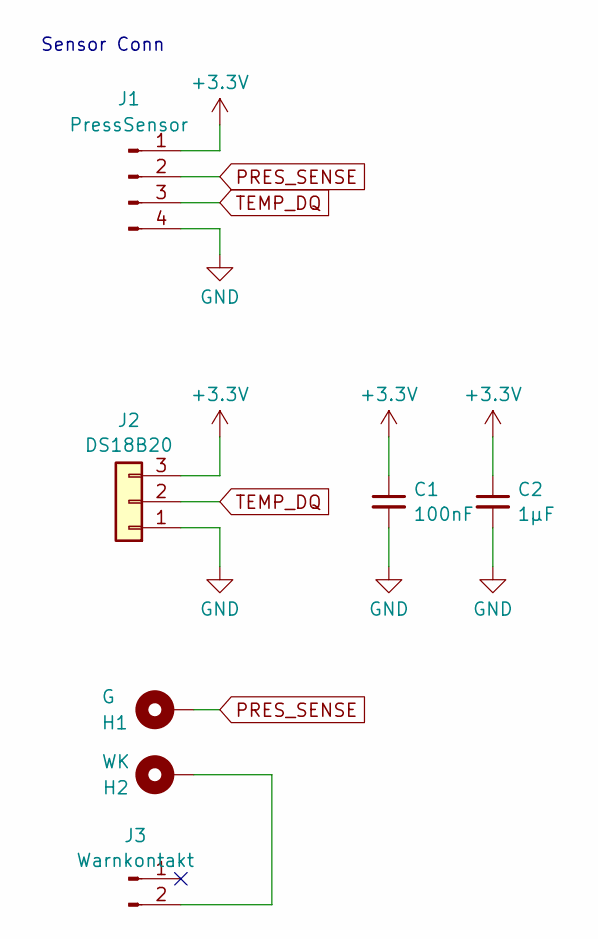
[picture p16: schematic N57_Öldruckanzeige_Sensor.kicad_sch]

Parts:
C1: 100nF; C_0603_1608Metric_Pad1.08x0.95mm_HandSolder
C2: 1μF; C_0603_1608Metric_Pad1.08x0.95mm_HandSolder
H1: G; MountingHole_4.3x6.2mm_M4_Pad
H2: WK; MountingHole_4.3x6.2mm_M4_Pad
J1: PressSensor; JST_PH_S4B-PH-K_1x04_P2.00mm_Horizontal
J2: DS18B20; PinHeader_1x03_P2.00mm_Vertical
J3: Warnkontakt; KFZ-2-POL-P5_DJ7021B-3.5-1121

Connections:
+3.3V: C1.1, C2.1, J1.1, J2.3
GND: C1.2, C2.2, J1.4, J2.1
unnamed: H2.1, J3.2
PRES_SENSE: H1.1, J1.2
TEMP_DQ: J1.3, J2.2

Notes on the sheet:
Sensor Conn

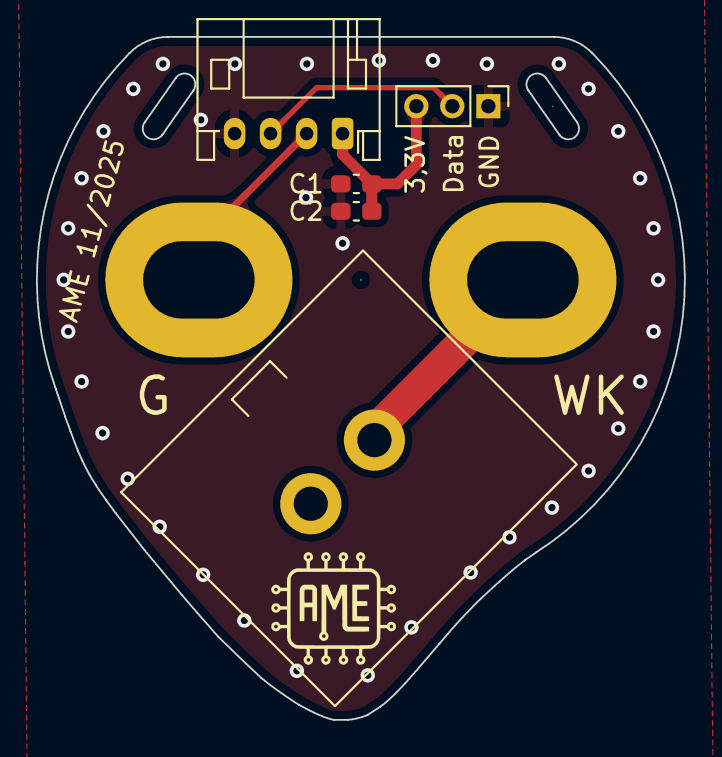
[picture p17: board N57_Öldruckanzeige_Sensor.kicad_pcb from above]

Board: 2 copper layers, 36.0 x 37.9 mm, 7 parts (0 on the bottom side), 5 nets.

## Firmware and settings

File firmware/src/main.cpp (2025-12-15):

#include <Arduino.h>
#include <WiFi.h>
#include <WebServer.h>
#include <DNSServer.h>
#include <OneWire.h>
#include <DallasTemperature.h>
#include <esp_wifi.h>

// =========================================================
// VERSIONEN
// =========================================================
#define SW_VERSION  "1.1"
#define HW_VERSION  "0.1"

// =========================================================
// WLAN
// =========================================================
const char* ssid     = "N57Oilpress";
const char* password = "D3848367";

// =========================================================
// BOOT-KALIBRIERUNG
// =========================================================
#define ENABLE_BOOT_CAL   0          // 1 = Auto-Kalibrierung
#define CAL_R_KNOWN       9.7f      // Sensor ~0 bar

// =========================================================
// PINS
// =========================================================
#define LED_WIFI_OK   3
#define LED_CLIENT    2
#define OIL_ADC       4
#define ONE_WIRE_BUS  5

// =========================================================
// ADC / HARDWARE
// =========================================================

// Spannung am oberen Ende des Spannungsteilers (gemessen!)
const float V_SUPPLY = 4.983f;

// ADC-Kalibrierung (aus Messpunkten ermittelt)
// Vadc = ADC_GAIN * adc + ADC_OFFSET
const float ADC_GAIN   = 0.000860761f;
const float ADC_OFFSET = 0.0288261f;

// Pullup-Widerstand (auto-kalibriert oder Fallback)
float R_PULLUP = 223.0f;

// VDO Messbereich
const float MAX_BAR = 5.0f;



// =========================================================
// GLOBALS
// =========================================================
DNSServer dnsServer;
WebServer server(80);

OneWire oneWire(ONE_WIRE_BUS);
DallasTemperature sensors(&oneWire);

// =========================================================
// ESP32 DIE TEMP (DEBUG)
// =========================================================
float espTempC() {
    return temperatureRead();
}

// =========================================================
// VDO LUT
// =========================================================
struct VdoPoint { float ohm; float bar; };

const VdoPoint VDO_TABLE[] = {
    { 10.0f, 0.0f },
    { 43.0f, 1.0f },
    { 79.0f, 2.0f },
    {111.0f, 3.0f },
    {136.0f, 4.0f },
    {184.0f, 5.0f }
};
const int VDO_SIZE = sizeof(VDO_TABLE) / sizeof(VdoPoint);

// =========================================================
// ADC → SPANNUNG → RSENSOR
// =========================================================
float adcToVoltage(uint16_t adc) {
    float v = ADC_GAIN * (float)adc + ADC_OFFSET;
    if (v < 0.0f) v = 0.0f;
    if (v > V_SUPPLY) v = V_SUPPLY;   // clamp
    return v;
}


float adcToRsensor(uint16_t adc) {
    float v = adcToVoltage(adc);
    if (v < 0.05f) return NAN;
    if (v > (V_SUPPLY - 0.05f)) return NAN;

    // 5V -> R_PULLUP -> Rsensor -> GND
    return R_PULLUP * v / (V_SUPPLY - v);
}


// =========================================================
// RSENSOR → BAR
// =========================================================
float rsensorToBar(float R) {
    if (isnan(R)) return NAN;
    if (R <= VDO_TABLE[0].ohm) return 0.0f;
    if (R >= VDO_TABLE[VDO_SIZE - 1].ohm) return MAX_BAR;

    for (int i = 0; i < VDO_SIZE - 1; i++) {
        if (R >= VDO_TABLE[i].ohm && R <= VDO_TABLE[i + 1].ohm) {
            return VDO_TABLE[i].bar +
                   (R - VDO_TABLE[i].ohm) *
                   (VDO_TABLE[i + 1].bar - VDO_TABLE[i].bar) /
                   (VDO_TABLE[i + 1].ohm - VDO_TABLE[i].ohm);
        }
    }
    return NAN;
}

// =========================================================
// IIR FILTER
// =========================================================
float oilIIR(float v) {
    static float last = NAN;
    const float alpha = 0.2f;
    if (isnan(last)) last = v;
    else last += alpha * (v - last);
    return last;
}

// =========================================================
// PULLUP-KALIBRIERUNG
// =========================================================
float calibratePullup(float Rs_known) {
    float sum = 0;
    int cnt = 0;
    delay(300);

    for (int i = 0; i < 16; i++) {
        float v = adcToVoltage(analogRead(OIL_ADC));
        if (v < 0.05f || v > 1.6f) continue;

        float rpu = Rs_known * (V_SUPPLY / v - 1.0f);
        if (rpu > 50 && rpu < 500) {
            sum += rpu;
            cnt++;
        }
        delay(5);
    }
    return cnt ? sum / cnt : R_PULLUP;
}



// =========================================================
// HTML UI
// =========================================================
const char MAIN_PAGE[] PROGMEM = R"====(
<!DOCTYPE html>
<html>
<head>
<meta charset="utf-8">
<title>N57 Oilpressure</title>

<style>
/* =======================================================
   Farb-Variablen (Default = TAG = GRÜN)
   ======================================================= */
:root{
    --main-color:#00ff66;
    --dim-color:rgba(0,255,102,0.55);
    --soft-color:rgba(0,255,102,0.35);
    --warn-color:#ff2a2a;
}

/* ================= NACHT = BMW-AMBER ================= */
body[data-theme="amber"]{
    --main-color:#ff7a18;
    --dim-color:rgba(255,122,24,0.55);
    --soft-color:rgba(255,122,24,0.35);
}

/* ================= Grundlayout ================= */
body{
    background:#000;
    color:var(--main-color);
    font-family:Arial, sans-serif;
    text-align:center;
    margin:0;
}

h1{
    font-weight:normal;
    letter-spacing:1px;
    color:var(--dim-color);
}

/* ================= Boxen ================= */
.box{
    border:1px solid var(--soft-color);
    margin:14px;
    padding:18px;
    border-radius:14px;
}

/* ================= Hauptanzeige ================= */
.flex{
    display:flex;
    justify-content:center;
    align-items:center;
    gap:50px;
}

.value{
    font-size:64px;
    font-weight:bold;
    text-shadow:0 0 10px var(--dim-color);
}

.unit{
    font-size:26px;
    color:var(--dim-color);
    margin-top:-6px;
}

/* ================= Warnung ================= */
span.warn{
    color:var(--warn-color);
    text-shadow:0 0 12px rgba(255,42,42,0.9);
}

span.warn.blink{
    animation:blink-red 1s infinite;
}

@keyframes blink-red{
    0%,50%,100%{opacity:1}
    25%,75%{opacity:0}
}

/* ================= Instrument ================= */
svg path{ stroke:var(--soft-color); }
svg line{ stroke:var(--main-color); }
svg circle{ fill:var(--main-color); }

/* ================= Debug ================= */
.box.debug{
    color:var(--dim-color);
    font-size:22px;
}

.debuggrid{
    display:grid;
    grid-template-columns:
        max-content max-content 100px max-content max-content;
    row-gap:10px;
    column-gap:8px;
    justify-content:start;
    text-align:left;
}
</style>

<script>
/* ================= TAG / NACHT ================= */
function updateThemeByTime(){
    const h = new Date().getHours();
    document.body.setAttribute("data-theme",(h>=20||h<6)?"amber":"green");
}

/* ================= Schwellen ================= */
const OIL_WARN_BAR = 0.8;
const TEMP_WARN_C = 120;

/* ================= Zeiger ================= */
function setNeedle(bar){
    if(bar===null) return;
    let a = -90 + (bar/5)*180;
    document.getElementById("needle")
        .setAttribute("transform","rotate("+a+" 150 140)");
}

/* ================= Update ================= */
async function update(){
    let j = await (await fetch("/data.json")).json();

    for(let k in j){
        let e=document.getElementById(k);
        if(e) e.innerText=j[k] ?? "--";
    }

    let oil=document.getElementById("oil_bar");
    oil.classList.remove("warn","blink");
    if(j.oil_bar!==null && j.oil_bar < OIL_WARN_BAR){
        oil.classList.add("warn","blink");
    }

    let temp=document.getElementById("oil_temp");
    temp.classList.remove("warn");
    if(j.oil_temp!==null && j.oil_temp > TEMP_WARN_C){
        temp.classList.add("warn");
    }

    setNeedle(j.oil_bar);
}

document.addEventListener("DOMContentLoaded",()=>{
    updateThemeByTime();
    setInterval(updateThemeByTime,300000);
    setInterval(update,1000);
});
</script>
</head>

<body>

<h1>N57 Oilpressure</h1>

<!-- ================= ÖLDRUCK ================= -->
<div class="box flex">
<svg width="340" height="200" viewBox="0 0 300 170">

    <path d="M40 140 A110 110 0 0 1 260 140"
          fill="none"
          stroke-width="10"/>

    <!-- Teilstriche -->
    <g transform="translate(150 140)">
        <g transform="rotate(-90)"><line x1="0" y1="-110" x2="0" y2="-100" stroke-width="2"/></g>
        <g transform="rotate(-72)"><line x1="0" y1="-110" x2="0" y2="-104" stroke-width="2"/></g>
        <g transform="rotate(-54)"><line x1="0" y1="-110" x2="0" y2="-100" stroke-width="2"/></g>
        <g transform="rotate(-36)"><line x1="0" y1="-110" x2="0" y2="-104" stroke-width="2"/></g>
        <g transform="rotate(-18)"><line x1="0" y1="-110" x2="0" y2="-100" stroke-width="2"/></g>
        <g transform="rotate(0)"><line x1="0" y1="-110" x2="0" y2="-104" stroke-width="2"/></g>
        <g transform="rotate(18)"><line x1="0" y1="-110" x2="0" y2="-100" stroke-width="2"/></g>
        <g transform="rotate(36)"><line x1="0" y1="-110" x2="0" y2="-104" stroke-width="2"/></g>
        <g transform="rotate(54)"><line x1="0" y1="-110" x2="0" y2="-100" stroke-width="2"/></g>
        <g transform="rotate(72)"><line x1="0" y1="-110" x2="0" y2="-104" stroke-width="2"/></g>
        <g transform="rotate(90)"><line x1="0" y1="-110" x2="0" y2="-100" stroke-width="2"/></g>
    </g>

    <line id="needle"
          x1="150" y1="140"
          x2="150" y2="45"
          stroke-width="5"/>

    <circle cx="150" cy="140" r="7"/>
</svg>

<div>
    <div class="value"><span id="oil_bar">--</span></div>
    <div class="unit">bar</div>
</div>
</div>

<!-- ================= ÖLTEMPERATUR ================= -->
<div class="box">
    <div class="value"><span id="oil_temp">--</span></div>
    <div class="unit">°C Oil</div>
</div>

<!-- ================= DEBUG ================= -->
<div class="box debug">
<b>Debug</b><br><br>
<div class="debuggrid">

<div>ADC:</div><div><span id="adc"></span></div>
<div></div>
<div>Vadc:</div><div><span id="vadc"></span> V</div>

<div>Rsensor:</div><div><span id="rs"></span> Ω</div>
<div></div>
<div>Bar raw:</div><div><span id="bar_raw"></span></div>

<div>ESP Temp:</div><div><span id="esp_temp"></span> °C</div>
<div></div>
<div>V_SUPPLY:</div><div><span id="v_supply"></span> V</div>

<div>R_PULLUP:</div><div><span id="rpu"></span> Ω</div>
<div></div><div></div><div></div>

<div>SW-Version:</div><div><span id="sw"></span></div>
<div></div>
<div>HW-Version:</div><div><span id="hw"></span></div>

</div>
</div>

</body>
</html>
)====";






// =========================================================
// JSON
// =========================================================
void handleDataJson() {
    uint16_t adc = analogRead(OIL_ADC);
    float vadc = adcToVoltage(adc);
    float Rs = adcToRsensor(adc);
    float bar_raw = rsensorToBar(Rs);
    float bar = oilIIR(bar_raw);

    sensors.requestTemperatures();
    float oilTemp = sensors.getTempCByIndex(0);
    if (oilTemp < -100) oilTemp = NAN;

    String j = "{";
    j += "\"adc\":"+String(adc)+",";
    j += "\"vadc\":"+String(vadc,3)+",";
    j += "\"rs\":"+(isnan(Rs)?"null":String(Rs,1))+",";
    j += "\"bar_raw\":"+(isnan(bar_raw)?"null":String(bar_raw,2))+",";
    j += "\"oil_bar\":"+(isnan(bar)?"null":String(bar,2))+",";
    j += "\"oil_temp\":"+(isnan(oilTemp)?"null":String(oilTemp,1))+",";
    j += "\"esp_temp\":"+String(espTempC(),1)+",";
    j += "\"v_supply\":"+String(V_SUPPLY,3)+",";
    j += "\"rpu\":"+String(R_PULLUP,1)+",";
    j += "\"sw\":\""+String(SW_VERSION)+"\",";
    j += "\"hw\":\""+String(HW_VERSION)+"\"}";
    server.send(200,"application/json",j);
}

// =========================================================
// SETUP / LOOP
// =========================================================
void setup() {
    Serial.begin(115200);
    pinMode(LED_WIFI_OK,OUTPUT);
    pinMode(LED_CLIENT,OUTPUT);

    analogReadResolution(12);
    analogSetAttenuation(ADC_11db);
    sensors.begin();

    #if ENABLE_BOOT_CAL
        R_PULLUP = calibratePullup(CAL_R_KNOWN);
    #else
        R_PULLUP = 220.0f;
    #endif

    WiFi.mode(WIFI_AP);
    WiFi.softAP(ssid,password);
    digitalWrite(LED_WIFI_OK,HIGH);

    dnsServer.start(53,"*",WiFi.softAPIP());
    server.on("/",[]{server.send(200,"text/html",MAIN_PAGE);});
    server.on("/data.json",handleDataJson);
    server.begin();
}

void loop() {
    dnsServer.processNextRequest();
    server.handleClient();
    wifi_sta_list_t l;
    esp_wifi_ap_get_sta_list(&l);
    digitalWrite(LED_CLIENT,l.num>0);
}

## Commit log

2025-12-15 Initial commit: ESP32 firmware and PCB design
    [BOM-N57_oildruckanzeige.csv, BOM-N57_Öldruckanzeige.csv, BOM-N57_Öldruckanzeige_Sensor.csv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]
2025-12-15 add pics and update README
    [BMW-N57_Oilpress_Case v3.3mf, BMW-N57_Oilpress_Case.f3d]

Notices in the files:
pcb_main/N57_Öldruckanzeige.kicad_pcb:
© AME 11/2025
